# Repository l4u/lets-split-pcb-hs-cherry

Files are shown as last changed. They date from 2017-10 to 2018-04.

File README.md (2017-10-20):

# lets-split-pcb-hs-cherry

Let's Split PCB for holtite socket only Cherry MX switches.

Based on [climbalima/let-s-Split-v2](https://github.com/climbalima/let-s-Split-v2).

## Overview



By crimping the socket to the through hole, it is possible to install without having to solder the axis of the switch and Pro Micro.

Cherry MX switch and several clone switches are available.

ALPS/Matias switch is ***NOT AVAILABLE***.

## Supported socket

- [TE CONNECTIVITY 8134-HC-8P2](http://www.te.com/jpn-ja/product-7-1437514-0.html)
- [TE CONNECTIVITY 8134-HC-8P3](http://www.te.com/jpn-ja/product-7-1437514-1.html)

## How to order PCB

There is a [releases page](https://github.com/haru-ake/lets-split-pcb-hs-cherry/releases) that zipped the Gerber file. You can use it to order to your preferred merchant.

I ordered it for [PCBGOGO](https://www.pcbgogo.jp/) and confirmed that I could manufacture it.

## How to crimp the socket

See youtube video.

How to make your keyboard PCB hot-swappable (http://www.youtube.com/watch?v=RB1Wm8y2Cw8)

## Points to note when crimping

***IMPORTANT!*** Since Pro Micro will be inserted from the bottom of the PCB, the switch will be inserted from the top of the PCB, so be careful of the orientation of the PCB when crimping the socket.

### Pro Micro

You can crimp the socket only to the through hole of the pin to be used. You can ***NOT*** crimp the socket into the through hole of the unused pin.

#### Rev 1.1.0 or higher



#### Up to rev 1.0.1



It is not possible to crimp the socket to the through hole where the socket is not stuck in the picture.

### Switches

Be careful not to mistake the position of the through hole.



## IMPORTANT NOTE

1. I have not confirmed the operation of some functions. Refer to the [Confirmed list](https://github.com/haru-ake/lets-split-pcb-hs-cherry/wiki/Confirmed-list) for details.
1. With PCB revision 1.1.0 or higher, the board size has been changed. If you want to use the original case of Let's Split Be careful.



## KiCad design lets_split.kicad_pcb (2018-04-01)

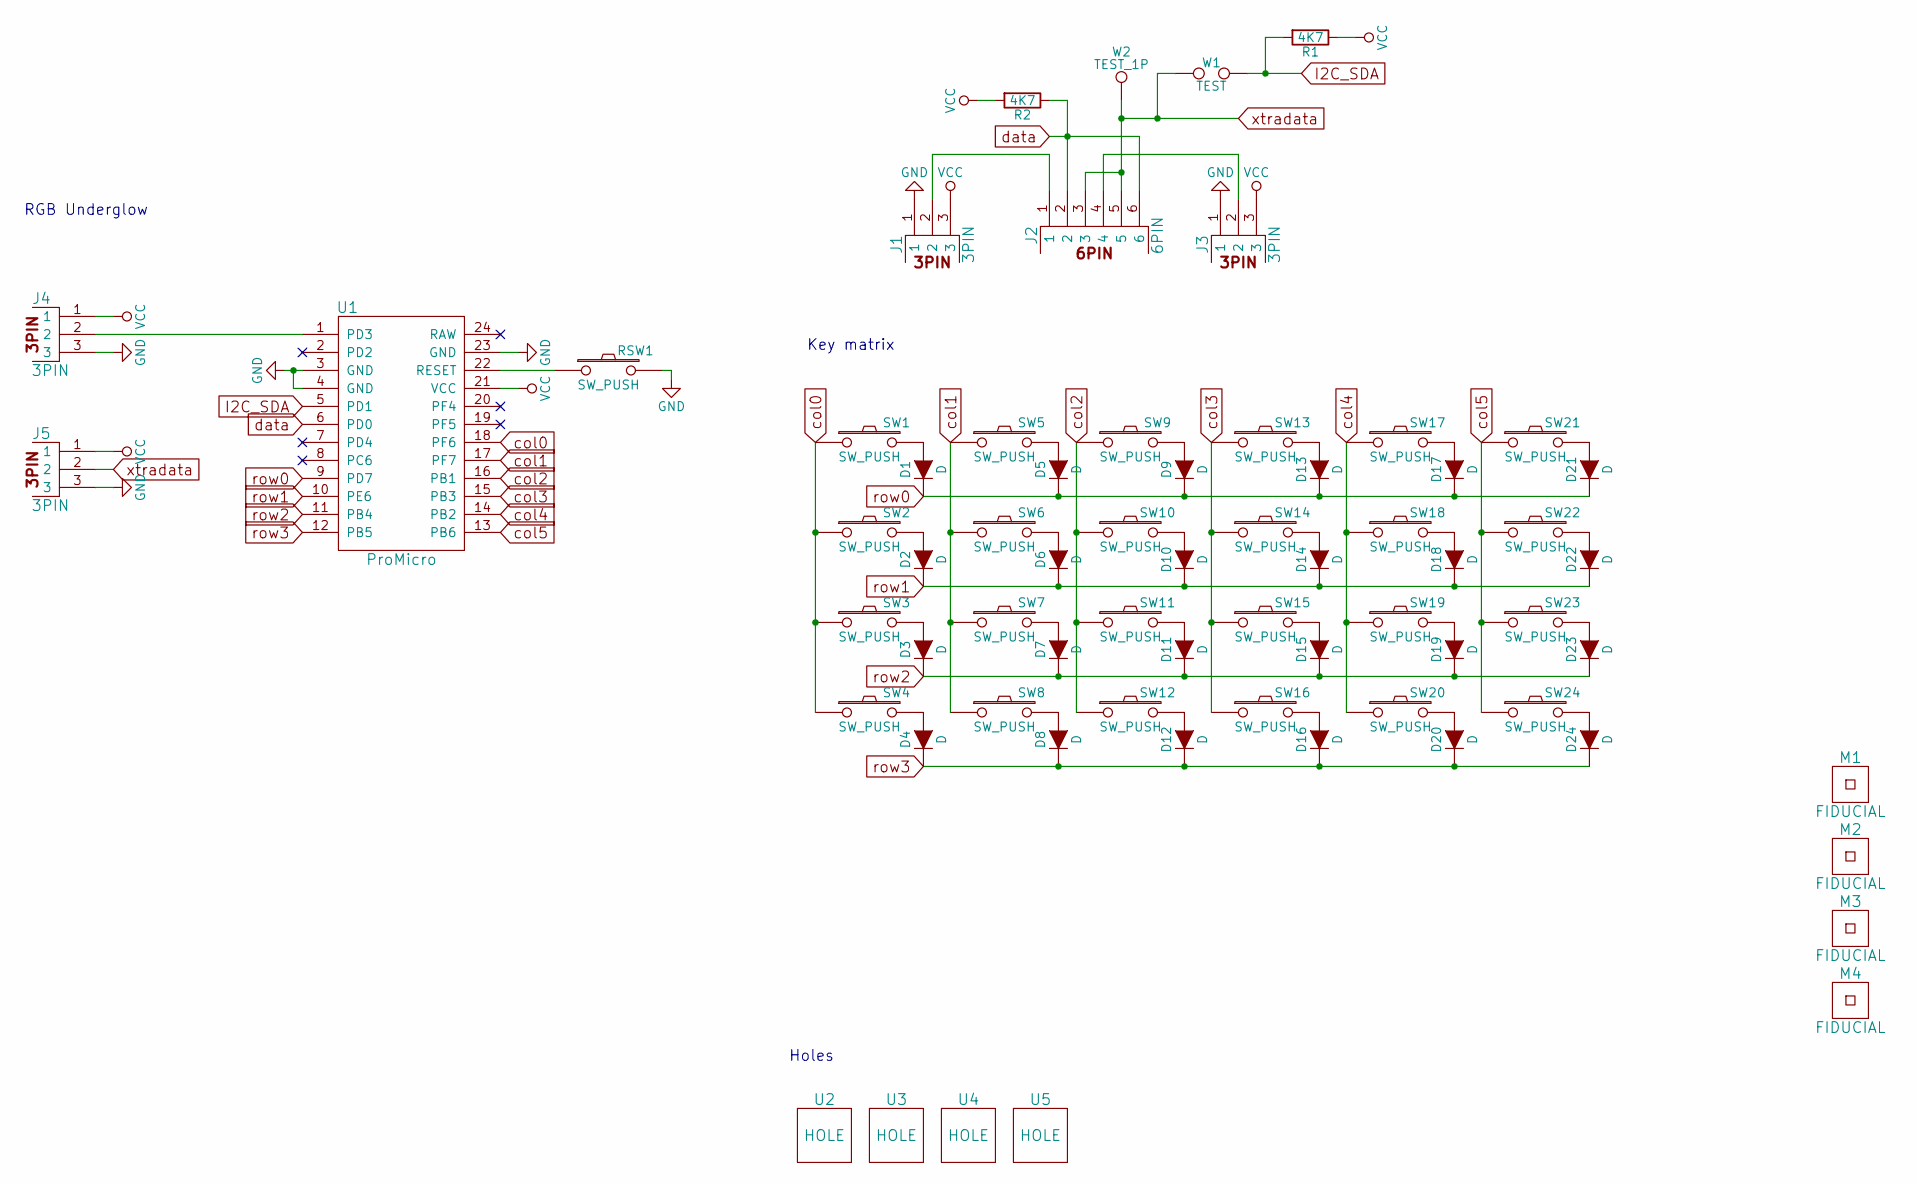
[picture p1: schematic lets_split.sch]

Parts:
D1, D2, D3, D4, D5, D6, D7, D8, D9, D10, D11, D12, D13, D14, D15, D16, D17, D18, D19, D20, D21, D22, D23, D24: D; Diode_TH_SOD123
J1, J3: 3PIN; SMD_JUMPER_2
J2: 6PIN; 4pin35mmAudio
J4, J5: 3PIN; CON3_SMD_BOTH
M1, M2, M3, M4: FIDUCIAL; Fiducial_Mark
R1, R2: 4K7; RESISTOR
RSW1: SW_PUSH; TACTILE_COMPATIBLE
SW1, SW2, SW3, SW4, SW5, SW6, SW7, SW8, SW9, SW10, SW11, SW12, SW13, SW14, SW15, SW16, SW17, SW18, SW19, SW20, SW21, SW22, SW23, SW24: SW_PUSH; MX-ALPs-PG1350-FLIP
U1: ProMicro
U2, U3, U4, U5: HOLE
W1: TEST; JUMPER_SMD_2DUB
W2: TEST_1P; SolderWirePad_single_2mmDrill

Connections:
GND: J1.1, J3.1, J4.3, J5.3, RSW1.2, U1.3 (GND), U1.4 (GND), U1.23 (GND)
I2C_SDA: R1.2, U1.5 (PD1), W1.2
unnamed: D1.2 (A), SW1.2
unnamed: D2.2 (A), SW2.2
unnamed: D3.2 (A), SW3.2
unnamed: D4.2 (A), SW4.2
unnamed: D5.2 (A), SW5.2
unnamed: D6.2 (A), SW6.2
unnamed: D7.2 (A), SW7.2
unnamed: D8.2 (A), SW8.2
unnamed: D9.2 (A), SW9.2
unnamed: D10.2 (A), SW10.2
unnamed: D11.2 (A), SW11.2
unnamed: D12.2 (A), SW12.2
unnamed: D13.2 (A), SW13.2
unnamed: D14.2 (A), SW14.2
unnamed: D15.2 (A), SW15.2
unnamed: D16.2 (A), SW16.2
unnamed: D17.2 (A), SW17.2
unnamed: D18.2 (A), SW18.2
unnamed: D19.2 (A), SW19.2
unnamed: D20.2 (A), SW20.2
unnamed: D21.2 (A), SW21.2
unnamed: D22.2 (A), SW22.2
unnamed: D23.2 (A), SW23.2
unnamed: D24.2 (A), SW24.2
unnamed: J1.2, J2.1
unnamed: J2.4, J3.2
unnamed: J4.2, U1.1 (PD3)
unnamed: RSW1.1, U1.22 (RESET)
VCC: J1.3, J3.3, J4.1, J5.1, R1.1, R2.2, U1.21 (VCC)
col0: SW1.1, SW2.1, SW3.1, SW4.1, U1.18 (PF6)
col1: SW5.1, SW6.1, SW7.1, SW8.1, U1.17 (PF7)
col2: SW9.1, SW10.1, SW11.1, SW12.1, U1.16 (PB1)
col3: SW13.1, SW14.1, SW15.1, SW16.1, U1.15 (PB3)
col4: SW17.1, SW18.1, SW19.1, SW20.1, U1.14 (PB2)
col5: SW21.1, SW22.1, SW23.1, SW24.1, U1.13 (PB6)
data: J2.2, J2.6, R2.1, U1.6 (PD0)
row0: D1.1 (K), D5.1 (K), D9.1 (K), D13.1 (K), D17.1 (K), D21.1 (K), U1.9 (PD7)
row1: D2.1 (K), D6.1 (K), D10.1 (K), D14.1 (K), D18.1 (K), D22.1 (K), U1.10 (PE6)
row2: D3.1 (K), D7.1 (K), D11.1 (K), D15.1 (K), D19.1 (K), D23.1 (K), U1.11 (PB4)
row3: D4.1 (K), D8.1 (K), D12.1 (K), D16.1 (K), D20.1 (K), D24.1 (K), U1.12 (PB5)

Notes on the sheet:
RGB Underglow
Holes
Key matrix

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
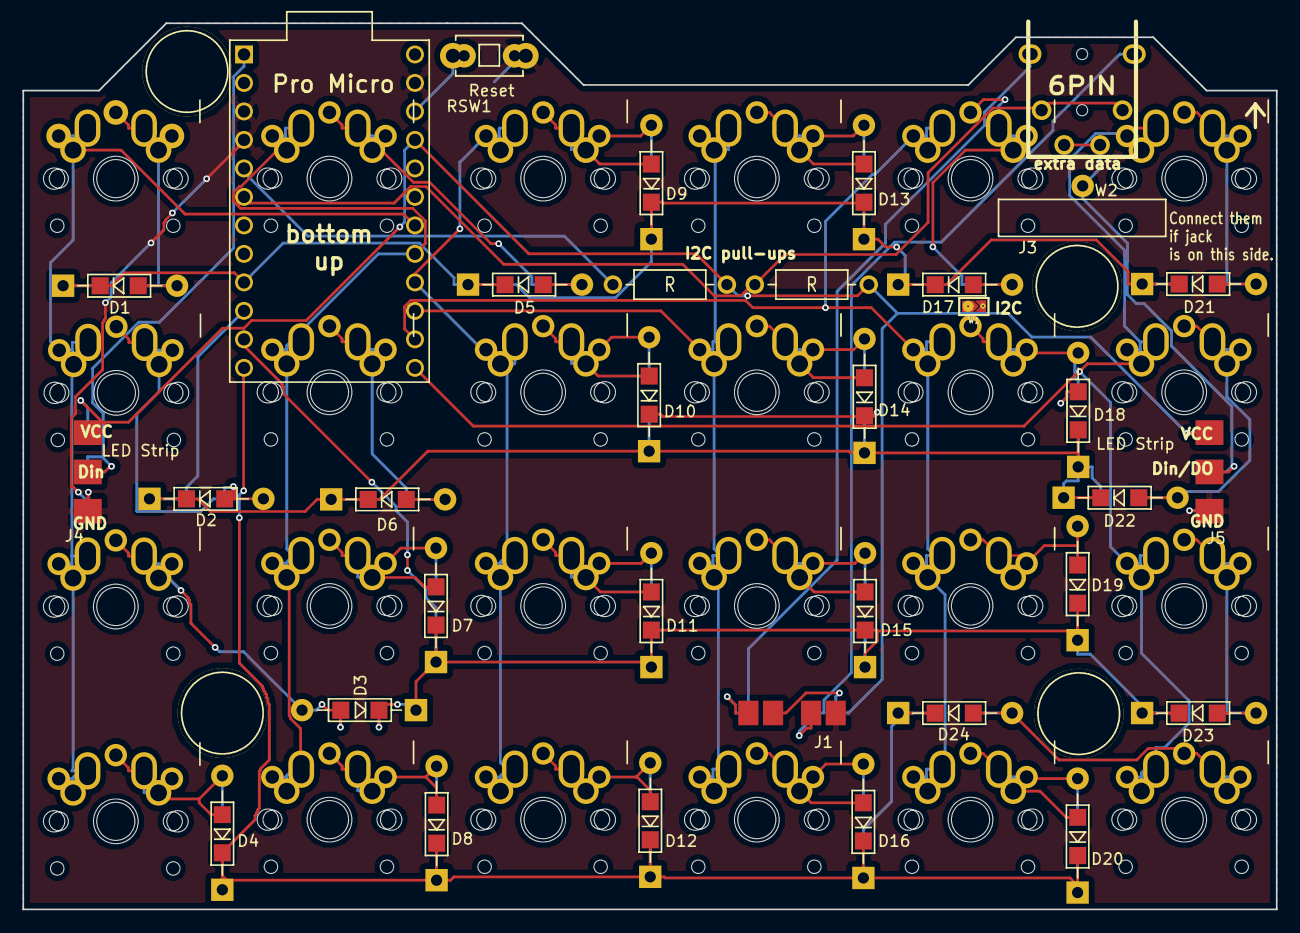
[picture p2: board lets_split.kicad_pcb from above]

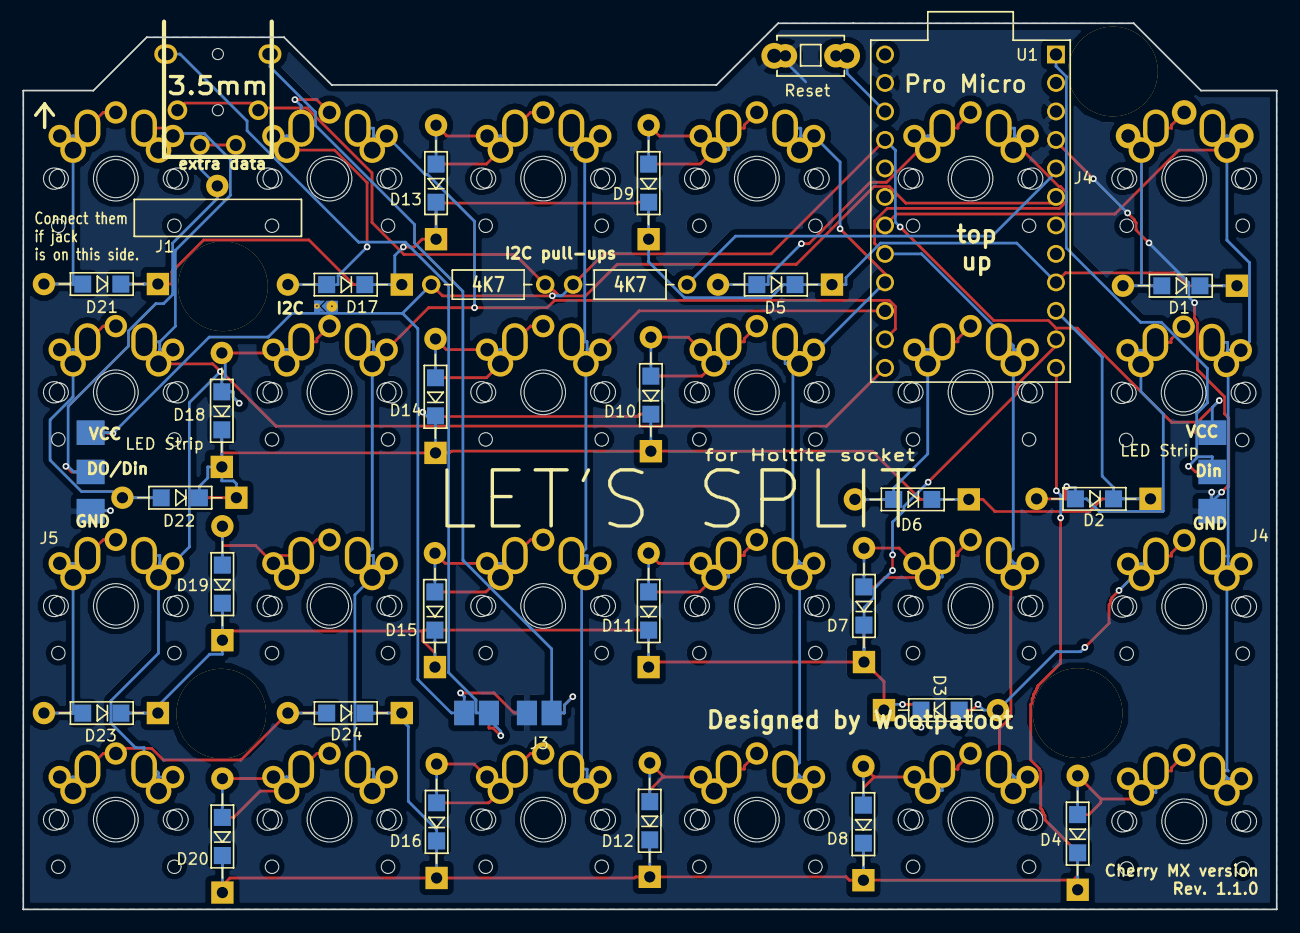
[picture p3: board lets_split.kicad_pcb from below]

Board: 2 copper layers, 111.8 x 79.0 mm, 63 parts (3 on the bottom side), 43 nets.

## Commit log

2017-08-25 remove cartoon characters protected by copyright
    [lets_split.kicad_pcb]
2017-08-25 tweak positions
    [lets_split.kicad_pcb]
2017-08-30 adjust the size of through holes to mount switches to fit holtite socket
    [lets_split.kicad_pcb]
2017-08-30 tweak wires
    [lets_split.kicad_pcb]
2017-08-30 adjust the size of through holes to mount Pro Micro to fit holtite socket
    [lets_split.kicad_pcb]
2017-08-30 tweak holes size for fixing to the switch plate
    [lets_split.kicad_pcb]
2017-08-30 tweak filled zone
    [lets_split.kicad_pcb]
2017-08-30 make the minimum hole diameter 0.3mm
    [lets_split.kicad_pcb]
2017-08-30 add revision on PCB
    [lets_split.kicad_pcb]
2017-09-09 first release
    [lets_split.kicad_pcb]
2017-09-09 development version
    [lets_split.kicad_pcb]
2017-09-12 tweak hole position for fixing to the switch plate
    [lets_split.kicad_pcb]
2017-09-12 bump version to 1.0.1
    [lets_split.kicad_pcb]
2017-09-28 bump version to 1.1.0
    [lets_split.kicad_pcb]
2018-04-01 Update hole
    [lets_split.kicad_pcb]
2018-04-01 Use promicro without socket
2018-04-01 Refill zone
    [lets_split.kicad_pcb]
2018-04-01 Add universal switch; fix prettylib
    [lets_split.kicad_pcb, lets_split.sch]
2018-04-01 Remove fiducial marker
    [lets_split.kicad_pcb]
2018-04-01 Use universal footprint
    [lets_split.kicad_pcb]
2018-04-01 Move components and run autoroute
    [lets_split.kicad_pcb]
